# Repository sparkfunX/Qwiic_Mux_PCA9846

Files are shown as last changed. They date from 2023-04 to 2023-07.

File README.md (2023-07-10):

SparkFun PCA9846 Qwiic I2C Mux
===========================================================

SparkX Qwiic Mux - PCA9846 (SPX-22362) (https://www.sparkfun.com/products/22362)

[*SparkX Qwiic Mux - PCA9846 (SPX-22362)*](https://www.sparkfun.com/products/22362)

Do you have too many sensors with the same I<sup>2</sup>C address? Connect them to the SparkX PCA9846 Qwiic Mux to get them all talking on the same bus! This Qwiic Mux enables communication with multiple I<sup>2</sup>C devices that have the same address. This Qwiic Mux also has eight configurable addresses of its own, allowing for up to 32 I<sup>2</sup>C buses on a single connection. To make it even easier to use this multiplexer, all communication is enacted exclusively via I<sup>2</sup>C, utilizing our handy Qwiic system.

The PCA9846 Qwiic Mux is very similar to our classic [8-channel Qwiic Mux](https://www.sparkfun.com/products/16784), except:

* It has four multiplexed Qwiic ports, plus Qwiic Main In and Out connections, on a super-cute 1" x 1" PCB
* The PCA9846 has a "Who Am I" (Device ID) product identification register which makes it _much_ easier to detect in auto-detect DataLogger / OpenLog applications.

Feel like supporting open source hardware? 
Buy a [board](https://www.sparkfun.com/products/22362) from SparkFun!

Repository Contents
-------------------

* **/Documents** - Datasheet for the PCA9846
* **/Hardware** - Eagle CAD files for the PCB, schematic and dimensions

Arduino Library
--------------

* **[Arduino Library](https://github.com/sparkfun/SparkFun_PCA9846_Mux_Arduino_Library)** - Arduino Library for the PCA9846 I<sup>2</sup>C Mux
* **[Installing an Arduino Library Guide](https://learn.sparkfun.com/tutorials/installing-an-arduino-library)** - Basic information on how to install an Arduino library.

Address Configuration
--------------

The PCA9846 actually supports 16 I<sup>2</sup>C addresses, but to implement all 16 we would have had to include another three solder jumpers.
This is a busy little board, so we decided to only implement 8 configurable addresses.

The PCA9846 appears on two I2C addresses:

* The mux address defined by the A0-A4 jumpers
* Address 0x7C - which is used to read the Device ID

The default mux address is 0x70 (unshifted). You can change it by opening and closing (soldering) the five address jumper pads as follows:

**Jumper Address Selection (Unshifted):**

| Address | A4 | A3 | A2 | A1 | A0 |
|---|---|---|---|---|---|
| 0x70 | Open | Open | Open | Open | **Closed** |
| 0x71 | Open | Open | Open | **Closed** | Open |
| 0x72 | Open | Open | **Closed** | Open | Open |
| 0x73 | Open | **Closed** | Open | Open | Open |
| 0x74 | **Closed** | Open | Open | Open | **Closed** |
| 0x75 | **Closed** | Open | Open | **Closed** | Open |
| 0x76 | **Closed** | Open | **Closed** | Open | Open |
| 0x77 | **Closed** | **Closed** | Open | Open | Open |

License Information
-------------------

This product is _**open source**_! 

Please use, reuse, and modify these files as you see fit. Please maintain attribution to SparkFun Electronics and release anything derivative under the same license.

Distributed as-is; no warranty is given.

- Your friends at SparkFun.

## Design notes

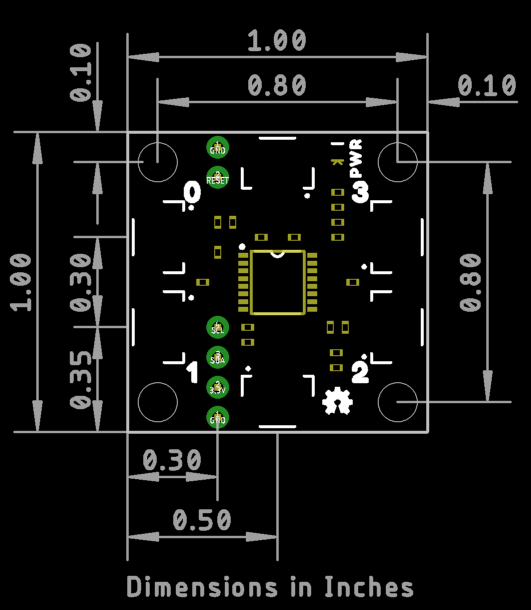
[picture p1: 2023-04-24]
Hardware/Dimensions.png

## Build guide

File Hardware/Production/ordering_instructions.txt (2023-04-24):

panel size, 169x117mm
PCB thickness, 1.6mm
number of layers, 2
soldermask color, Black
silkscreen color, White
oz copper, 1oz
finish, HASL lead free
stencils, top
pcs per panel, 24
min trace width, 0.1778mm / 0.0070in
min drill size, 0.3000mm / 0.0118in

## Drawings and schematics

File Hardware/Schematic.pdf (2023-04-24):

SD1 SD1 | SC1
SC1 SC1 | SD2

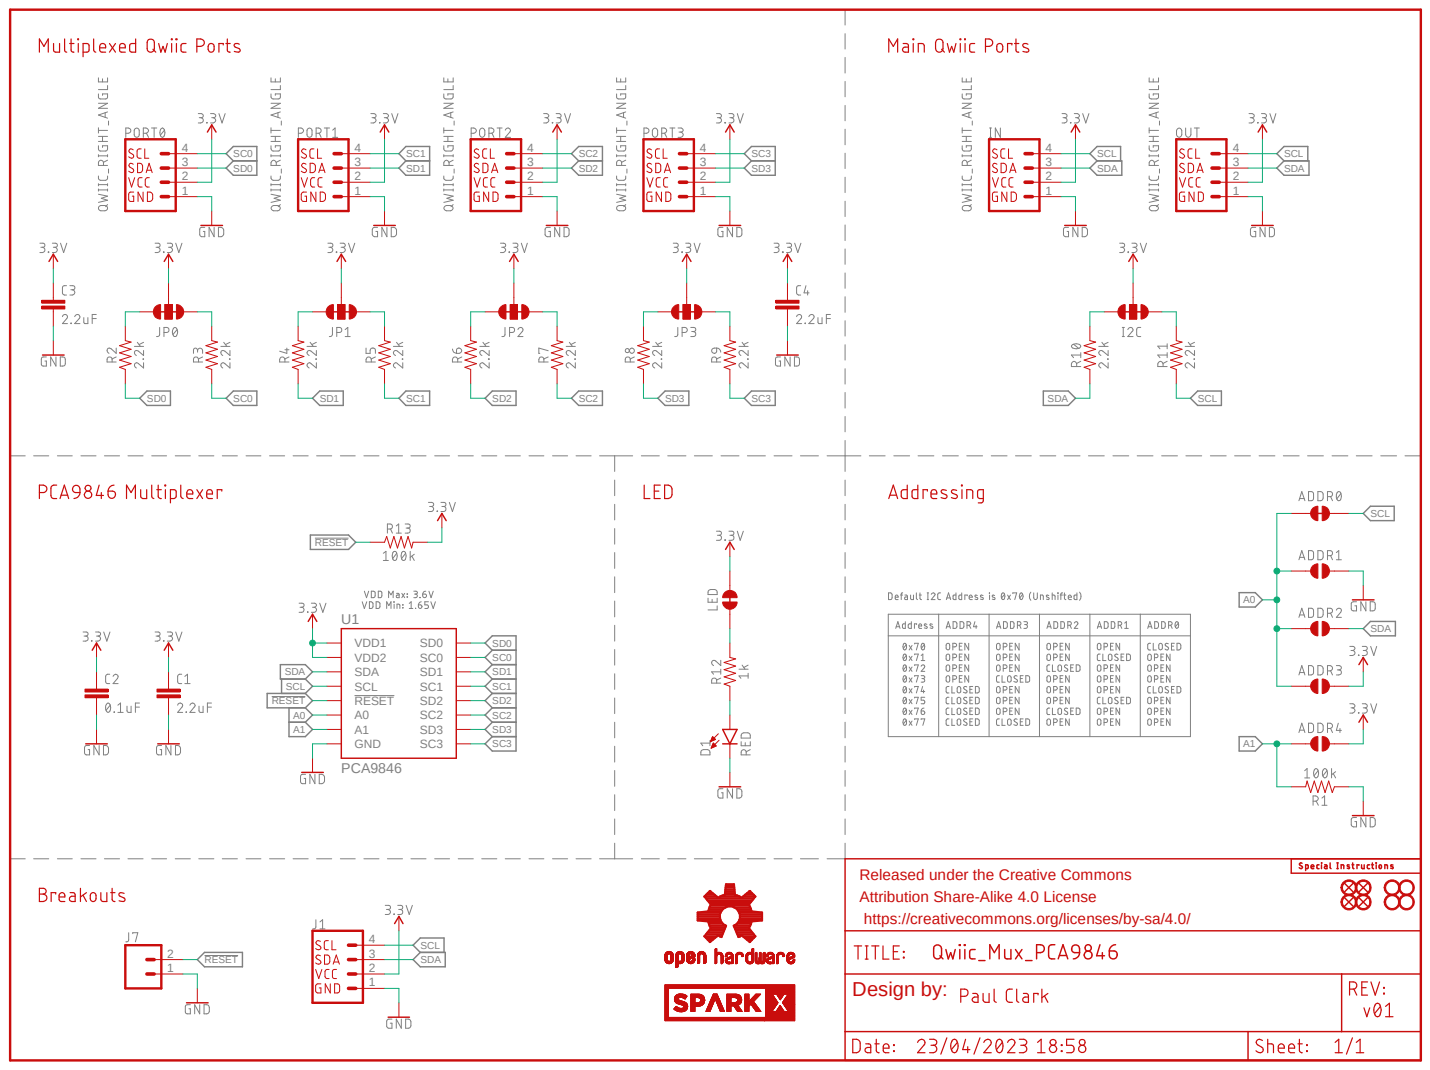
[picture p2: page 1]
PCA9846 SD0 A1SDA; SC3 SC3 SDA; SDA; SCL; RESET A0; A1 Released under the Creative Commons; Design by:

SCL RESET RESET

SD3 SC2 SC3 SD2 SD1 SC0 SC1 VDD2 U1
SCL A0VDD1 RESET GND

Attribution Share-Alike 4.0 License
https://creativecommons.org/licenses/by-sa/4.0/

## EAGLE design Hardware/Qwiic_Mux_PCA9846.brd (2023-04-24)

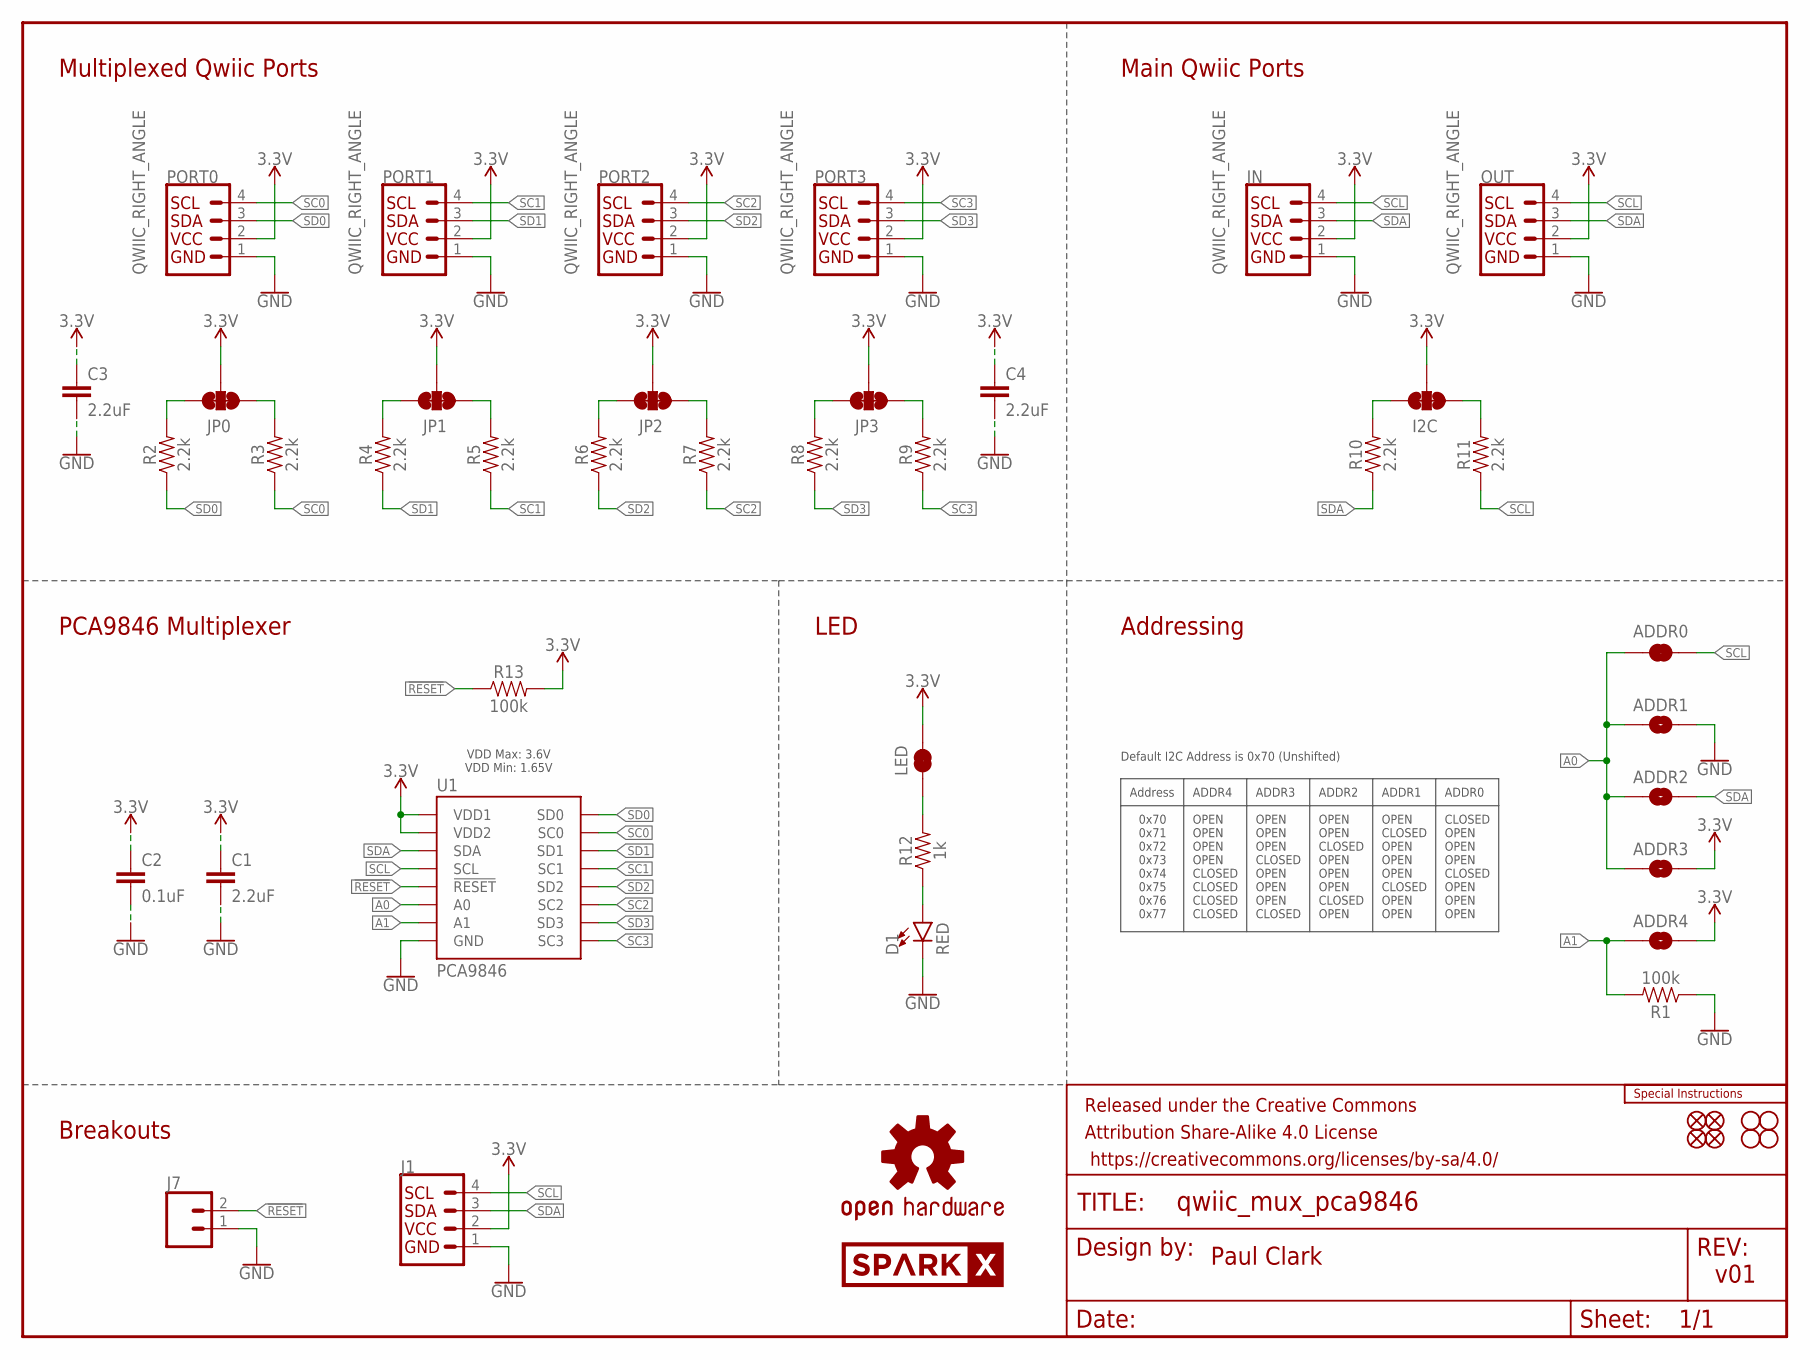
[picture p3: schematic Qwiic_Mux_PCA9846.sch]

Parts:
ADDR0: JUMPER-SMT_2_NC_TRACE_SILK; SMT-JUMPER_2_NC_TRACE_SILK
ADDR1, ADDR2, ADDR3, ADDR4: JUMPER-SMT_2_NO_SILK; SMT-JUMPER_2_NO_SILK
C1, C3, C4: 2.2uF; 0402-TIGHT
C2: 0.1uF; 0402-TIGHT
D1: RED; LED-0603
FD1, FD2, FD3, FD4: FIDUCIAL1X2; FIDUCIAL-1X2
FRAME1: FRAME-LETTER; CREATIVE_COMMONS
H1, H2, H3, H4: STAND-OFF
I2C: JUMPER-SMT_3_2-NC_TRACE_SILK; SMT-JUMPER_3_2-NC_TRACE_SILK
IN: QWIIC_RIGHT_ANGLE; JST04_1MM_RA
J1: I2C_STANDARD_NO_SILK; 1X04_NO_SILK
J7: CONN_021X02_NO_SILK; 1X02_NO_SILK
JP0, JP1, JP2, JP3: JUMPER-SMT_3_2-NC_TRACE_SILK; SMT-JUMPER_3_2-NC_TRACE_SILK
LED: JUMPER-SMT_2_NC_TRACE_SILK; SMT-JUMPER_2_NC_TRACE_SILK
LOGO1: SPECIAL_INSTRUCTIONS-ORDERING; ORDERING_INSTRUCTIONS
LOGO4: OSHW-LOGOMINI; OSHW-LOGO-MINI
OUT: QWIIC_RIGHT_ANGLE; JST04_1MM_RA
PORT0, PORT1, PORT2, PORT3: QWIIC_RIGHT_ANGLE; JST04_1MM_RA
R1, R13: 100k; 0402-TIGHT
R2, R3, R4, R5, R6, R7, R8, R9, R10, R11: 2.2k; 0402-TIGHT
R12: 1k; 0402-TIGHT
U1: PCA9846; SOT403-1
U$1: SPARKX-LOGO3; SPARKX-SMALL

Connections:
3.3V: ADDR3.2, ADDR4.2, C1.1, C2.1, C3.1, C4.1, I2C.2, IN.2, J1.2, JP0.2, JP1.2, JP2.2, JP3.2, LED.2, OUT.2, PORT0.2, PORT1.2, PORT2.2, PORT3.2, R13.2, U1.1 (VDD1), U1.16 (VDD2)
!RESET!: J7.2, R13.1, U1.3 (!RESET)
A0: ADDR0.1, ADDR1.1, ADDR2.1, ADDR3.1, U1.2 (A0)
A1: ADDR4.1, R1.2, U1.13 (A1)
GND: ADDR1.2, C1.2, C2.2, C3.2, C4.2, D1.C, IN.1, J1.1, J7.1, OUT.1, PORT0.1, PORT1.1, PORT2.1, PORT3.1, R1.1, U1.8 (GND)
unnamed: JP0.3, R2.2
unnamed: JP0.1, R3.2
unnamed: JP1.3, R4.2
unnamed: JP1.1, R5.2
unnamed: JP2.3, R6.2
unnamed: JP2.1, R7.2
unnamed: JP3.3, R8.2
unnamed: JP3.1, R9.2
unnamed: I2C.3, R10.2
unnamed: I2C.1, R11.2
unnamed: LED.1, R12.2
unnamed: D1.A, R12.1
SC0: PORT0.4, R3.1, U1.5 (SC0)
SC1: PORT1.4, R5.1, U1.7 (SC1)
SC2: PORT2.4, R7.1, U1.10 (SC2)
SC3: PORT3.4, R9.1, U1.12 (SC3)
SCL: ADDR0.2, IN.4, J1.4, OUT.4, R11.1, U1.14 (SCL)
SD0: PORT0.3, R2.1, U1.4 (SD0)
SD1: PORT1.3, R4.1, U1.6 (SD1)
SD2: PORT2.3, R6.1, U1.9 (SD2)
SD3: PORT3.3, R8.1, U1.11 (SD3)
SDA: ADDR2.2, IN.3, J1.3, OUT.3, R10.1, U1.15 (SDA)

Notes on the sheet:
Multiplexed Qwiic Ports
Main Qwiic Ports
PCA9846 Multiplexer
Addressing
Default I2C Address is 0x70 (Unshifted)
Address
ADDR4
ADDR3
ADDR2
ADDR1
ADDR0
0x70 0x71 0x72 0x73 0x74 0x75 0x76 0x77
OPEN OPEN OPEN OPEN CLOSED CLOSED CLOSED CLOSED
OPEN OPEN OPEN CLOSED OPEN OPEN OPEN CLOSED
CLOSED OPEN OPEN OPEN CLOSED OPEN OPEN OPEN
OPEN CLOSED OPEN OPEN OPEN CLOSED OPEN OPEN
OPEN OPEN CLOSED OPEN OPEN OPEN CLOSED OPEN
Paul Clark
v01
Breakouts
LED
VDD Max: 3.6V VDD Min: 1.65V

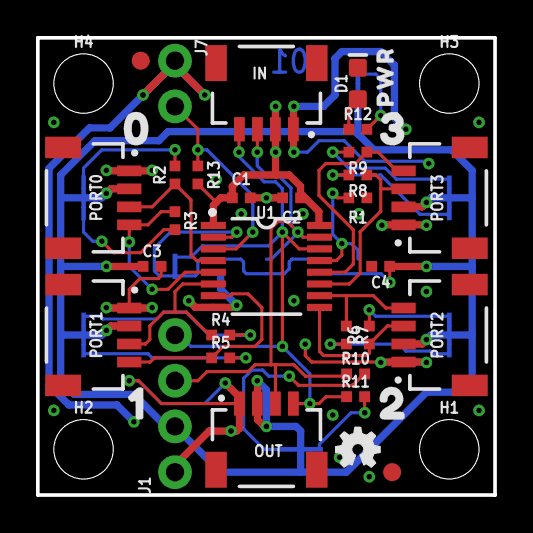
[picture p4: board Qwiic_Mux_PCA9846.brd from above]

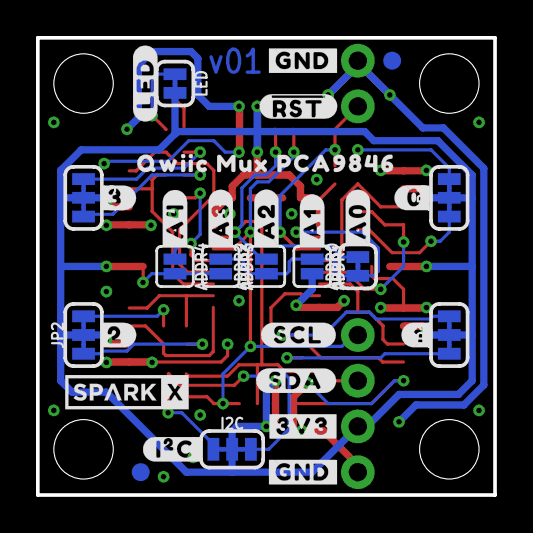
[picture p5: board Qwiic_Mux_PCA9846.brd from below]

Board: 2 copper layers, 25.4 x 25.4 mm, 73 parts (32 on the bottom side), 27 nets.

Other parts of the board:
U$2: PWR43214
U$3: 043215
U$4: 10
U$5: 211
U$6: 3212
U$7: ##RST##8
U$8: #0#9
U$9: #1#9
U$10: #2#9
U$11: #3#9
U$12: #3V3#7
U$13: #A0#0
U$14: #A1#1
U$15: #A2#2
U$16: #A3#3
U$17: #A4#4
U$18, U$19: #GND#7
U$21: #SCL#5
U$22: #SDA#6
U$23: #LED#0
U$24: QWIIC_MUX_PCA98461
U$25: #I�C#0

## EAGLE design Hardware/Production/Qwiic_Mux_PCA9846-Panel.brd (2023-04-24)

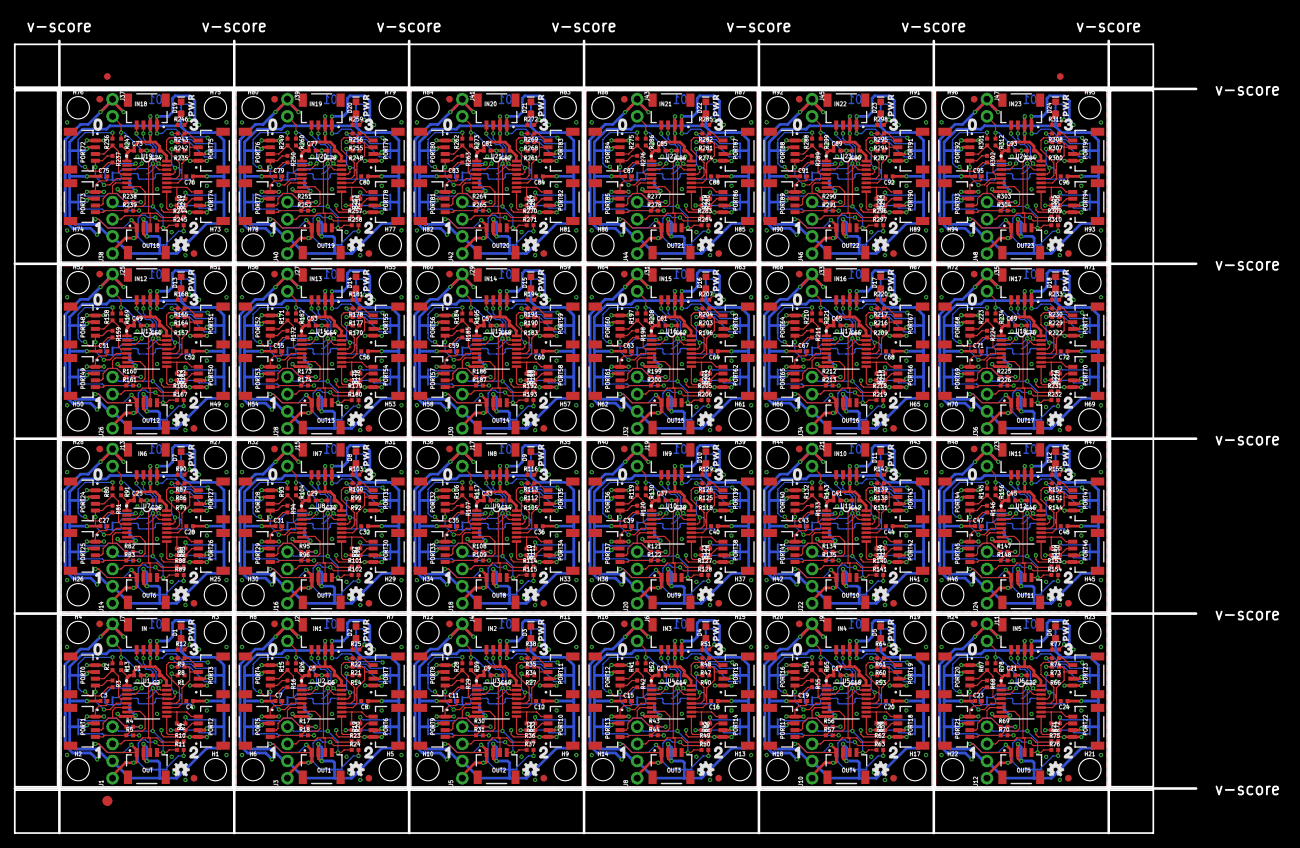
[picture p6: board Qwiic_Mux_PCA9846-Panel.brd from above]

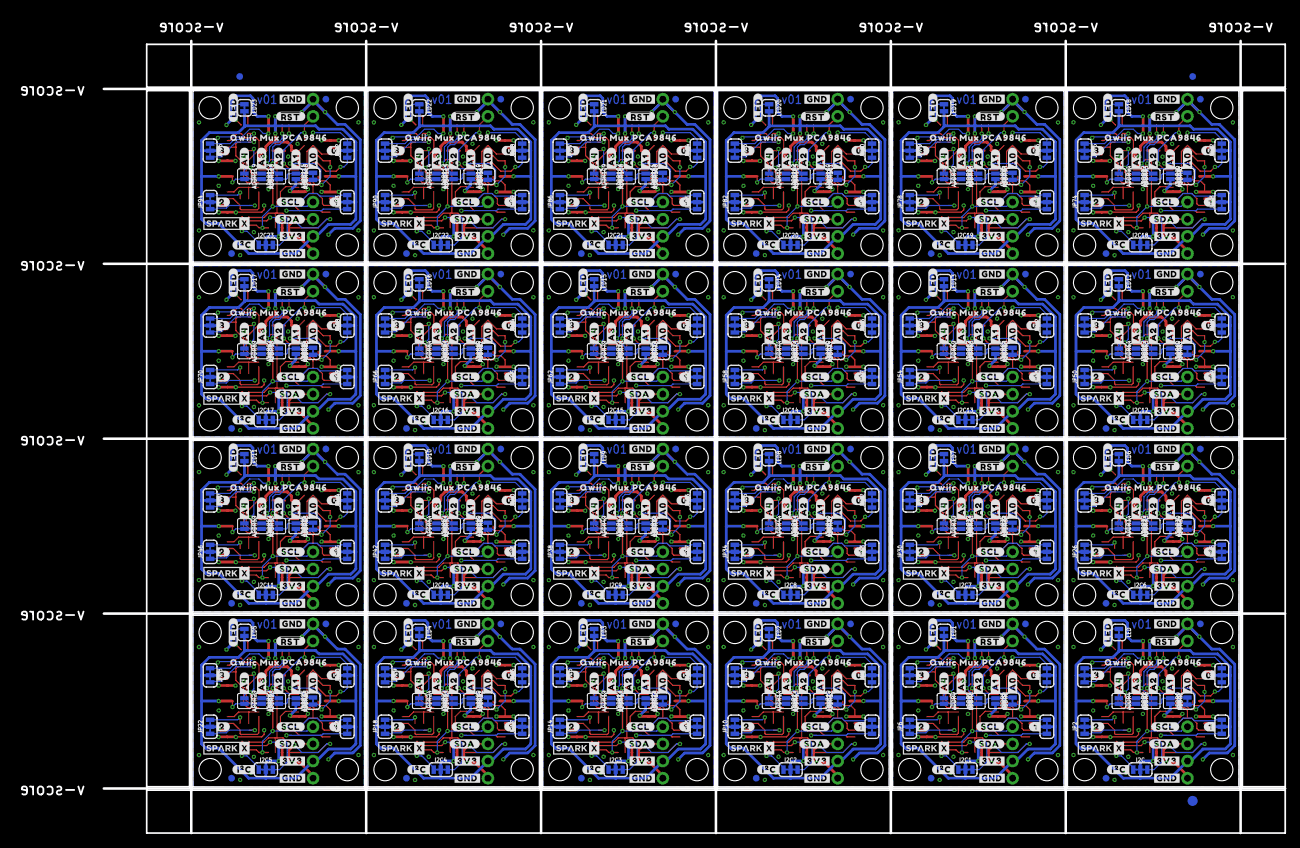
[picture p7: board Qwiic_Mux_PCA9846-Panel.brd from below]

Board: 2 copper layers, 175.0 x 117.3 mm, 1710 parts (771 on the bottom side), 648 nets.

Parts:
ADDR0, ADDR5, ADDR10, ADDR15, ADDR20, ADDR25, ADDR30, ADDR35, ADDR40, ADDR45, ADDR50, ADDR55, ADDR60, ADDR65, ADDR70, ADDR75, ADDR80, ADDR85, ADDR90, ADDR95, ADDR100, ADDR105, ADDR110, ADDR115: JUMPER-SMT_2_NC_TRACE_SILK; SMT-JUMPER_2_NC_TRACE_SILK
ADDR1, ADDR2, ADDR3, ADDR4, ADDR6, ADDR7, ADDR8, ADDR9, ADDR11, ADDR12, ADDR13, ADDR14, ADDR16, ADDR17, ADDR18, ADDR19, ADDR21, ADDR22, ADDR23, ADDR24, ADDR26, ADDR27, ADDR28, ADDR29, ADDR31, ADDR32, ADDR33, ADDR34, ADDR36, ADDR37, ADDR38, ADDR39, ADDR41, ADDR42, ADDR43, ADDR44, ADDR46, ADDR47, ADDR48, ADDR49, ADDR51, ADDR52, ADDR53, ADDR54, ADDR56, ADDR57, ADDR58, ADDR59, ADDR61, ADDR62, ADDR63, ADDR64, ADDR66, ADDR67, ADDR68, ADDR69, ADDR71, ADDR72, ADDR73, ADDR74, ADDR76, ADDR77, ADDR78, ADDR79, ADDR81, ADDR82, ADDR83, ADDR84, ADDR86, ADDR87, ADDR88, ADDR89, ADDR91, ADDR92, ADDR93, ADDR94, ADDR96, ADDR97, ADDR98, ADDR99, ADDR101, ADDR102, ADDR103, ADDR104, ADDR106, ADDR107, ADDR108, ADDR109, ADDR111, ADDR112, ADDR113, ADDR114, ADDR116, ADDR117, ADDR118, ADDR119: JUMPER-SMT_2_NO_SILK; SMT-JUMPER_2_NO_SILK
C1, C3, C4, C5, C7, C8, C9, C11, C12, C13, C15, C16, C17, C19, C20, C21, C23, C24, C25, C27, C28, C29, C31, C32, C33, C35, C36, C37, C39, C40, C41, C43, C44, C45, C47, C48, C49, C51, C52, C53, C55, C56, C57, C59, C60, C61, C63, C64, C65, C67, C68, C69, C71, C72, C73, C75, C76, C77, C79, C80, C81, C83, C84, C85, C87, C88, C89, C91, C92, C93, C95, C96: 2.2uF; 0402-TIGHT
C2, C6, C10, C14, C18, C22, C26, C30, C34, C38, C42, C46, C50, C54, C58, C62, C66, C70, C74, C78, C82, C86, C90, C94: 0.1uF; 0402-TIGHT
D1, D2, D3, D4, D5, D6, D7, D8, D9, D10, D11, D12, D13, D14, D15, D16, D17, D18, D19, D20, D21, D22, D23, D24: RED; LED-0603
E$1, E$2, E$3, E$4: FIDUCIAL-1X2
E$5, E$6: FIDUCIAL-1.5X3
FD1, FD2, FD3, FD4, FD5, FD6, FD7, FD8, FD9, FD10, FD11, FD12, FD13, FD14, FD15, FD16, FD17, FD18, FD19, FD20, FD21, FD22, FD23, FD24, FD25, FD26, FD27, FD28, FD29, FD30, FD31, FD32, FD33, FD34, FD35, FD36, FD37, FD38, FD39, FD40, FD41, FD42, FD43, FD44, FD45, FD46, FD47, FD48, FD49, FD50, FD51, FD52, FD53, FD54, FD55, FD56, FD57, FD58, FD59, FD60, FD61, FD62, FD63, FD64, FD65, FD66, FD67, FD68, FD69, FD70, FD71, FD72, FD73, FD74, FD75, FD76, FD77, FD78, FD79, FD80, FD81, FD82, FD83, FD84, FD85, FD86, FD87, FD88, FD89, FD90, FD91, FD92, FD93, FD94, FD95, FD96: FIDUCIAL1X2; FIDUCIAL-1X2
H1, H2, H3, H4, H5, H6, H7, H8, H9, H10, H11, H12, H13, H14, H15, H16, H17, H18, H19, H20, H21, H22, H23, H24, H25, H26, H27, H28, H29, H30, H31, H32, H33, H34, H35, H36, H37, H38, H39, H40, H41, H42, H43, H44, H45, H46, H47, H48, H49, H50, H51, H52, H53, H54, H55, H56, H57, H58, H59, H60, H61, H62, H63, H64, H65, H66, H67, H68, H69, H70, H71, H72, H73, H74, H75, H76, H77, H78, H79, H80, H81, H82, H83, H84, H85, H86, H87, H88, H89, H90, H91, H92, H93, H94, H95, H96: STAND-OFF
I2C, I2C1, I2C2, I2C3, I2C4, I2C5, I2C6, I2C7, I2C8, I2C9, I2C10, I2C11, I2C12, I2C13, I2C14, I2C15, I2C16, I2C17, I2C18, I2C19, I2C20, I2C21, I2C22, I2C23: JUMPER-SMT_3_2-NC_TRACE_SILK; SMT-JUMPER_3_2-NC_TRACE_SILK
IN, IN1, IN2, IN3, IN4, IN5, IN6, IN7, IN8, IN9, IN10, IN11, IN12, IN13, IN14, IN15, IN16, IN17, IN18, IN19, IN20, IN21, IN22, IN23: QWIIC_RIGHT_ANGLE; JST04_1MM_RA
J1, J3, J5, J8, J10, J12, J14, J16, J18, J20, J22, J24, J26, J28, J30, J32, J34, J36, J38, J40, J42, J44, J46, J48: 1X04_NO_SILK
J2, J4, J6, J7, J9, J11, J13, J15, J17, J19, J21, J23, J25, J27, J29, J31, J33, J35, J37, J39, J41, J43, J45, J47: 1X02_NO_SILK
JP0, JP1, JP2, JP3, JP4, JP5, JP6, JP7, JP8, JP9, JP10, JP11, JP12, JP13, JP14, JP15, JP16, JP17, JP18, JP19, JP20, JP21, JP22, JP23, JP24, JP25, JP26, JP27, JP28, JP29, JP30, JP31, JP32, JP33, JP34, JP35, JP36, JP37, JP38, JP39, JP40, JP41, JP42, JP43, JP44, JP45, JP46, JP47, JP48, JP49, JP50, JP51, JP52, JP53, JP54, JP55, JP56, JP57, JP58, JP59, JP60, JP61, JP62, JP63, JP64, JP65, JP66, JP67, JP68, JP69, JP70, JP71, JP72, JP73, JP74, JP75, JP76, JP77, JP78, JP79, JP80, JP81, JP82, JP83, JP84, JP85, JP86, JP87, JP88, JP89, JP90, JP91, JP92, JP93, JP94, JP95: JUMPER-SMT_3_2-NC_TRACE_SILK; SMT-JUMPER_3_2-NC_TRACE_SILK
LED, LED1, LED2, LED3, LED4, LED5, LED6, LED7, LED8, LED9, LED10, LED11, LED12, LED13, LED14, LED15, LED16, LED17, LED18, LED19, LED20, LED21, LED22, LED23: JUMPER-SMT_2_NC_TRACE_SILK; SMT-JUMPER_2_NC_TRACE_SILK
LOGO1, LOGO2, LOGO3, LOGO4, LOGO5, LOGO6, LOGO7, LOGO8, LOGO9, LOGO10, LOGO11, LOGO12, LOGO13, LOGO14, LOGO15, LOGO16, LOGO17, LOGO18, LOGO19, LOGO20, LOGO21, LOGO22, LOGO23, LOGO24: OSHW-LOGOMINI; OSHW-LOGO-MINI
OUT, OUT1, OUT2, OUT3, OUT4, OUT5, OUT6, OUT7, OUT8, OUT9, OUT10, OUT11, OUT12, OUT13, OUT14, OUT15, OUT16, OUT17, OUT18, OUT19, OUT20, OUT21, OUT22, OUT23: QWIIC_RIGHT_ANGLE; JST04_1MM_RA
PORT0, PORT1, PORT2, PORT3, PORT4, PORT5, PORT6, PORT7, PORT8, PORT9, PORT10, PORT11, PORT12, PORT13, PORT14, PORT15, PORT16, PORT17, PORT18, PORT19, PORT20, PORT21, PORT22, PORT23, PORT24, PORT25, PORT26, PORT27, PORT28, PORT29, PORT30, PORT31, PORT32, PORT33, PORT34, PORT35, PORT36, PORT37, PORT38, PORT39, PORT40, PORT41, PORT42, PORT43, PORT44, PORT45, PORT46, PORT47, PORT48, PORT49, PORT50, PORT51, PORT52, PORT53, PORT54, PORT55, PORT56, PORT57, PORT58, PORT59, PORT60, PORT61, PORT62, PORT63, PORT64, PORT65, PORT66, PORT67, PORT68, PORT69, PORT70, PORT71, PORT72, PORT73, PORT74, PORT75, PORT76, PORT77, PORT78, PORT79, PORT80, PORT81, PORT82, PORT83, PORT84, PORT85, PORT86, PORT87, PORT88, PORT89, PORT90, PORT91, PORT92, PORT93, PORT94, PORT95: QWIIC_RIGHT_ANGLE; JST04_1MM_RA
R1, R13, R14, R26, R27, R39, R40, R52, R53, R65, R66, R78, R79, R91, R92, R104, R105, R117, R118, R130, R131, R143, R144, R156, R157, R169, R170, R182, R183, R195, R196, R208, R209, R221, R222, R234, R235, R247, R248, R260, R261, R273, R274, R286, R287, R299, R300, R312: 100k; 0402-TIGHT
R2, R3, R4, R5, R6, R7, R8, R9, R10, R11, R15, R16, R17, R18, R19, R20, R21, R22, R23, R24, R28, R29, R30, R31, R32, R33, R34, R35, R36, R37, R41, R42, R43, R44, R45, R46, R47, R48, R49, R50, R54, R55, R56, R57, R58, R59, R60, R61, R62, R63, R67, R68, R69, R70, R71, R72, R73, R74, R75, R76, R80, R81, R82, R83, R84, R85, R86, R87, R88, R89, R93, R94, R95, R96, R97, R98, R99, R100, R101, R102, R106, R107, R108, R109, R110, R111, R112, R113, R114, R115, R119, R120, R121, R122, R123, R124, R125, R126, R127, R128, R132, R133, R134, R135, R136, R137, R138, R139, R140, R141, R145, R146, R147, R148, R149, R150, R151, R152, R153, R154, R158, R159, R160, R161, R162, R163, R164, R165, R166, R167, R171, R172, R173, R174, R175, R176, R177, R178, R179, R180, R184, R185, R186, R187, R188, R189, R190, R191, R192, R193, R197, R198, R199, R200, R201, R202, R203, R204, R205, R206, R210, R211, R212, R213, R214, R215, R216, R217, R218, R219, R223, R224, R225, R226, R227, R228, R229, R230, R231, R232, R236, R237, R238, R239, R240, R241, R242, R243, R244, R245, R249, R250, R251, R252, R253, R254, R255, R256, R257, R258, R262, R263, R264, R265, R266, R267, R268, R269, R270, R271, R275, R276, R277, R278, R279, R280, R281, R282, R283, R284, R288, R289, R290, R291, R292, R293, R294, R295, R296, R297, R301, R302, R303, R304, R305, R306, R307, R308, R309, R310: 2.2k; 0402-TIGHT
R12, R25, R38, R51, R64, R77, R90, R103, R116, R129, R142, R155, R168, R181, R194, R207, R220, R233, R246, R259, R272, R285, R298, R311: 1k; 0402-TIGHT
U1, U2, U3, U4, U5, U6, U7, U8, U9, U10, U11, U12, U13, U14, U15, U16, U17, U18, U19, U20, U21, U22, U23, U24: PCA9846; SOT403-1
U$1, U$20, U$49, U$73, U$97, U$121, U$145, U$169, U$193, U$217, U$241, U$265, U$289, U$313, U$337, U$361, U$385, U$409, U$433, U$457, U$481, U$505, U$529, U$553: SPARKX-LOGO3; SPARKX-SMALL
U$2, U$26, U$50, U$74, U$98, U$122, U$146, U$170, U$194, U$218, U$242, U$266, U$290, U$314, U$338, U$362, U$386, U$410, U$434, U$458, U$482, U$506, U$530, U$554: PWR43214
U$3, U$27, U$51, U$75, U$99, U$123, U$147, U$171, U$195, U$219, U$243, U$267, U$291, U$315, U$339, U$363, U$387, U$411, U$435, U$459, U$483, U$507, U$531, U$555: 043215
U$4, U$28, U$52, U$76, U$100, U$124, U$148, U$172, U$196, U$220, U$244, U$268, U$292, U$316, U$340, U$364, U$388, U$412, U$436, U$460, U$484, U$508, U$532, U$556: 10
U$5, U$29, U$53, U$77, U$101, U$125, U$149, U$173, U$197, U$221, U$245, U$269, U$293, U$317, U$341, U$365, U$389, U$413, U$437, U$461, U$485, U$509, U$533, U$557: 211
U$6, U$30, U$54, U$78, U$102, U$126, U$150, U$174, U$198, U$222, U$246, U$270, U$294, U$318, U$342, U$366, U$390, U$414, U$438, U$462, U$486, U$510, U$534, U$558: 3212
U$7, U$31, U$55, U$79, U$103, U$127, U$151, U$175, U$199, U$223, U$247, U$271, U$295, U$319, U$343, U$367, U$391, U$415, U$439, U$463, U$487, U$511, U$535, U$559: ##RST##8
U$8, U$32, U$56, U$80, U$104, U$128, U$152, U$176, U$200, U$224, U$248, U$272, U$296, U$320, U$344, U$368, U$392, U$416, U$440, U$464, U$488, U$512, U$536, U$560: #0#9
U$9, U$33, U$57, U$81, U$105, U$129, U$153, U$177, U$201, U$225, U$249, U$273, U$297, U$321, U$345, U$369, U$393, U$417, U$441, U$465, U$489, U$513, U$537, U$561: #1#9
U$10, U$34, U$58, U$82, U$106, U$130, U$154, U$178, U$202, U$226, U$250, U$274, U$298, U$322, U$346, U$370, U$394, U$418, U$442, U$466, U$490, U$514, U$538, U$562: #2#9
U$11, U$35, U$59, U$83, U$107, U$131, U$155, U$179, U$203, U$227, U$251, U$275, U$299, U$323, U$347, U$371, U$395, U$419, U$443, U$467, U$491, U$515, U$539, U$563: #3#9
U$12, U$36, U$60, U$84, U$108, U$132, U$156, U$180, U$204, U$228, U$252, U$276, U$300, U$324, U$348, U$372, U$396, U$420, U$444, U$468, U$492, U$516, U$540, U$564: #3V3#7
U$13, U$37, U$61, U$85, U$109, U$133, U$157, U$181, U$205, U$229, U$253, U$277, U$301, U$325, U$349, U$373, U$397, U$421, U$445, U$469, U$493, U$517, U$541, U$565: #A0#0
U$14, U$38, U$62, U$86, U$110, U$134, U$158, U$182, U$206, U$230, U$254, U$278, U$302, U$326, U$350, U$374, U$398, U$422, U$446, U$470, U$494, U$518, U$542, U$566: #A1#1
U$15, U$39, U$63, U$87, U$111, U$135, U$159, U$183, U$207, U$231, U$255, U$279, U$303, U$327, U$351, U$375, U$399, U$423, U$447, U$471, U$495, U$519, U$543, U$567: #A2#2
U$16, U$40, U$64, U$88, U$112, U$136, U$160, U$184, U$208, U$232, U$256, U$280, U$304, U$328, U$352, U$376, U$400, U$424, U$448, U$472, U$496, U$520, U$544, U$568: #A3#3
U$17, U$41, U$65, U$89, U$113, U$137, U$161, U$185, U$209, U$233, U$257, U$281, U$305, U$329, U$353, U$377, U$401, U$425, U$449, U$473, U$497, U$521, U$545, U$569: #A4#4
U$18, U$19, U$42, U$43, U$66, U$67, U$90, U$91, U$114, U$115, U$138, U$139, U$162, U$163, U$186, U$187, U$210, U$211, U$234, U$235, U$258, U$259, U$282, U$283, U$306, U$307, U$330, U$331, U$354, U$355, U$378, U$379, U$402, U$403, U$426, U$427, U$450, U$451, U$474, U$475, U$498, U$499, U$522, U$523, U$546, U$547, U$570, U$571: #GND#7
U$21, U$44, U$68, U$92, U$116, U$140, U$164, U$188, U$212, U$236, U$260, U$284, U$308, U$332, U$356, U$380, U$404, U$428, U$452, U$476, U$500, U$524, U$548, U$572: #SCL#5
U$22, U$45, U$69, U$93, U$117, U$141, U$165, U$189, U$213, U$237, U$261, U$285, U$309, U$333, U$357, U$381, U$405, U$429, U$453, U$477, U$501, U$525, U$549, U$573: #SDA#6
U$23, U$46, U$70, U$94, U$118, U$142, U$166, U$190, U$214, U$238, U$262, U$286, U$310, U$334, U$358, U$382, U$406, U$430, U$454, U$478, U$502, U$526, U$550, U$574: #LED#0
U$24, U$47, U$71, U$95, U$119, U$143, U$167, U$191, U$215, U$239, U$263, U$287, U$311, U$335, U$359, U$383, U$407, U$431, U$455, U$479, U$503, U$527, U$551, U$575: QWIIC_MUX_PCA98461
U$25, U$48, U$72, U$96, U$120, U$144, U$168, U$192, U$216, U$240, U$264, U$288, U$312, U$336, U$360, U$384, U$408, U$432, U$456, U$480, U$504, U$528, U$552, U$576: #I�C#0

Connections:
3.3V: ADDR3.2, ADDR4.2, C1.1, C2.1, C3.1, C4.1, I2C.2, IN.2, J1.2, JP0.2, JP1.2, JP2.2, JP3.2, LED.2, OUT.2, PORT0.2, PORT1.2, PORT2.2, PORT3.2, R13.2, U1.1, U1.16
3.3V1: ADDR8.2, ADDR9.2, C5.1, C6.1, C7.1, C8.1, I2C1.2, IN1.2, J3.2, JP4.2, JP5.2, JP6.2, JP7.2, LED1.2, OUT1.2, PORT4.2, PORT5.2, PORT6.2, PORT7.2, R26.2, U2.1, U2.16
3.3V2: ADDR13.2, ADDR14.2, C9.1, C10.1, C11.1, C12.1, I2C2.2, IN2.2, J5.2, JP8.2, JP9.2, JP10.2, JP11.2, LED2.2, OUT2.2, PORT8.2, PORT9.2, PORT10.2, PORT11.2, R39.2, U3.1, U3.16
3.3V3: ADDR18.2, ADDR19.2, C13.1, C14.1, C15.1, C16.1, I2C3.2, IN3.2, J8.2, JP12.2, JP13.2, JP14.2, JP15.2, LED3.2, OUT3.2, PORT12.2, PORT13.2, PORT14.2, PORT15.2, R52.2, U4.1, U4.16
3.3V4: ADDR23.2, ADDR24.2, C17.1, C18.1, C19.1, C20.1, I2C4.2, IN4.2, J10.2, JP16.2, JP17.2, JP18.2, JP19.2, LED4.2, OUT4.2, PORT16.2, PORT17.2, PORT18.2, PORT19.2, R65.2, U5.1, U5.16
3.3V5: ADDR28.2, ADDR29.2, C21.1, C22.1, C23.1, C24.1, I2C5.2, IN5.2, J12.2, JP20.2, JP21.2, JP22.2, JP23.2, LED5.2, OUT5.2, PORT20.2, PORT21.2, PORT22.2, PORT23.2, R78.2, U6.1, U6.16
3.3V6: ADDR33.2, ADDR34.2, C25.1, C26.1, C27.1, C28.1, I2C6.2, IN6.2, J14.2, JP24.2, JP25.2, JP26.2, JP27.2, LED6.2, OUT6.2, PORT24.2, PORT25.2, PORT26.2, PORT27.2, R91.2, U7.1, U7.16
3.3V7: ADDR38.2, ADDR39.2, C29.1, C30.1, C31.1, C32.1, I2C7.2, IN7.2, J16.2, JP28.2, JP29.2, JP30.2, JP31.2, LED7.2, OUT7.2, PORT28.2, PORT29.2, PORT30.2, PORT31.2, R104.2, U8.1, U8.16
3.3V8: ADDR43.2, ADDR44.2, C33.1, C34.1, C35.1, C36.1, I2C8.2, IN8.2, J18.2, JP32.2, JP33.2, JP34.2, JP35.2, LED8.2, OUT8.2, PORT32.2, PORT33.2, PORT34.2, PORT35.2, R117.2, U9.1, U9.16
3.3V9: ADDR48.2, ADDR49.2, C37.1, C38.1, C39.1, C40.1, I2C9.2, IN9.2, J20.2, JP36.2, JP37.2, JP38.2, JP39.2, LED9.2, OUT9.2, PORT36.2, PORT37.2, PORT38.2, PORT39.2, R130.2, U10.1, U10.16
3.3V10: ADDR53.2, ADDR54.2, C41.1, C42.1, C43.1, C44.1, I2C10.2, IN10.2, J22.2, JP40.2, JP41.2, JP42.2, JP43.2, LED10.2, OUT10.2, PORT40.2, PORT41.2, PORT42.2, PORT43.2, R143.2, U11.1, U11.16
3.3V11: ADDR58.2, ADDR59.2, C45.1, C46.1, C47.1, C48.1, I2C11.2, IN11.2, J24.2, JP44.2, JP45.2, JP46.2, JP47.2, LED11.2, OUT11.2, PORT44.2, PORT45.2, PORT46.2, PORT47.2, R156.2, U12.1, U12.16
3.3V12: ADDR63.2, ADDR64.2, C49.1, C50.1, C51.1, C52.1, I2C12.2, IN12.2, J26.2, JP48.2, JP49.2, JP50.2, JP51.2, LED12.2, OUT12.2, PORT48.2, PORT49.2, PORT50.2, PORT51.2, R169.2, U13.1, U13.16
3.3V13: ADDR68.2, ADDR69.2, C53.1, C54.1, C55.1, C56.1, I2C13.2, IN13.2, J28.2, JP52.2, JP53.2, JP54.2, JP55.2, LED13.2, OUT13.2, PORT52.2, PORT53.2, PORT54.2, PORT55.2, R182.2, U14.1, U14.16
3.3V14: ADDR73.2, ADDR74.2, C57.1, C58.1, C59.1, C60.1, I2C14.2, IN14.2, J30.2, JP56.2, JP57.2, JP58.2, JP59.2, LED14.2, OUT14.2, PORT56.2, PORT57.2, PORT58.2, PORT59.2, R195.2, U15.1, U15.16
3.3V15: ADDR78.2, ADDR79.2, C61.1, C62.1, C63.1, C64.1, I2C15.2, IN15.2, J32.2, JP60.2, JP61.2, JP62.2, JP63.2, LED15.2, OUT15.2, PORT60.2, PORT61.2, PORT62.2, PORT63.2, R208.2, U16.1, U16.16
3.3V16: ADDR83.2, ADDR84.2, C65.1, C66.1, C67.1, C68.1, I2C16.2, IN16.2, J34.2, JP64.2, JP65.2, JP66.2, JP67.2, LED16.2, OUT16.2, PORT64.2, PORT65.2, PORT66.2, PORT67.2, R221.2, U17.1, U17.16
3.3V17: ADDR88.2, ADDR89.2, C69.1, C70.1, C71.1, C72.1, I2C17.2, IN17.2, J36.2, JP68.2, JP69.2, JP70.2, JP71.2, LED17.2, OUT17.2, PORT68.2, PORT69.2, PORT70.2, PORT71.2, R234.2, U18.1, U18.16
3.3V18: ADDR93.2, ADDR94.2, C73.1, C74.1, C75.1, C76.1, I2C18.2, IN18.2, J38.2, JP72.2, JP73.2, JP74.2, JP75.2, LED18.2, OUT18.2, PORT72.2, PORT73.2, PORT74.2, PORT75.2, R247.2, U19.1, U19.16
3.3V19: ADDR98.2, ADDR99.2, C77.1, C78.1, C79.1, C80.1, I2C19.2, IN19.2, J40.2, JP76.2, JP77.2, JP78.2, JP79.2, LED19.2, OUT19.2, PORT76.2, PORT77.2, PORT78.2, PORT79.2, R260.2, U20.1, U20.16
3.3V20: ADDR103.2, ADDR104.2, C81.1, C82.1, C83.1, C84.1, I2C20.2, IN20.2, J42.2, JP80.2, JP81.2, JP82.2, JP83.2, LED20.2, OUT20.2, PORT80.2, PORT81.2, PORT82.2, PORT83.2, R273.2, U21.1, U21.16
3.3V21: ADDR108.2, ADDR109.2, C85.1, C86.1, C87.1, C88.1, I2C21.2, IN21.2, J44.2, JP84.2, JP85.2, JP86.2, JP87.2, LED21.2, OUT21.2, PORT84.2, PORT85.2, PORT86.2, PORT87.2, R286.2, U22.1, U22.16
3.3V22: ADDR113.2, ADDR114.2, C89.1, C90.1, C91.1, C92.1, I2C22.2, IN22.2, J46.2, JP88.2, JP89.2, JP90.2, JP91.2, LED22.2, OUT22.2, PORT88.2, PORT89.2, PORT90.2, PORT91.2, R299.2, U23.1, U23.16
3.3V23: ADDR118.2, ADDR119.2, C93.1, C94.1, C95.1, C96.1, I2C23.2, IN23.2, J48.2, JP92.2, JP93.2, JP94.2, JP95.2, LED23.2, OUT23.2, PORT92.2, PORT93.2, PORT94.2, PORT95.2, R312.2, U24.1, U24.16
!RESET!: J7.2, R13.1, U1.3
!RESET!1: J2.2, R26.1, U2.3
!RESET!2: J4.2, R39.1, U3.3
!RESET!3: J6.2, R52.1, U4.3
!RESET!4: J9.2, R65.1, U5.3
!RESET!5: J11.2, R78.1, U6.3
!RESET!6: J13.2, R91.1, U7.3
!RESET!7: J15.2, R104.1, U8.3
!RESET!8: J17.2, R117.1, U9.3
!RESET!9: J19.2, R130.1, U10.3
!RESET!10: J21.2, R143.1, U11.3
!RESET!11: J23.2, R156.1, U12.3
!RESET!12: J25.2, R169.1, U13.3
!RESET!13: J27.2, R182.1, U14.3
!RESET!14: J29.2, R195.1, U15.3
!RESET!15: J31.2, R208.1, U16.3
!RESET!16: J33.2, R221.1, U17.3
!RESET!17: J35.2, R234.1, U18.3
!RESET!18: J37.2, R247.1, U19.3
!RESET!19: J39.2, R260.1, U20.3
!RESET!20: J41.2, R273.1, U21.3
!RESET!21: J43.2, R286.1, U22.3
!RESET!22: J45.2, R299.1, U23.3
!RESET!23: J47.2, R312.1, U24.3
A0: ADDR0.1, ADDR1.1, ADDR2.1, ADDR3.1, U1.2
A1: ADDR4.1, R1.2, U1.13
A2: ADDR5.1, ADDR6.1, ADDR7.1, ADDR8.1, U2.2
A3: ADDR9.1, R14.2, U2.13
A4: ADDR10.1, ADDR11.1, ADDR12.1, ADDR13.1, U3.2
A5: ADDR14.1, R27.2, U3.13
A6: ADDR15.1, ADDR16.1, ADDR17.1, ADDR18.1, U4.2
A7: ADDR19.1, R40.2, U4.13
A8: ADDR20.1, ADDR21.1, ADDR22.1, ADDR23.1, U5.2
A9: ADDR24.1, R53.2, U5.13
A10: ADDR25.1, ADDR26.1, ADDR27.1, ADDR28.1, U6.2
A11: ADDR29.1, R66.2, U6.13
A12: ADDR30.1, ADDR31.1, ADDR32.1, ADDR33.1, U7.2
A13: ADDR34.1, R79.2, U7.13
A14: ADDR35.1, ADDR36.1, ADDR37.1, ADDR38.1, U8.2
A15: ADDR39.1, R92.2, U8.13
A16: ADDR40.1, ADDR41.1, ADDR42.1, ADDR43.1, U9.2
A17: ADDR44.1, R105.2, U9.13
A18: ADDR45.1, ADDR46.1, ADDR47.1, ADDR48.1, U10.2
A19: ADDR49.1, R118.2, U10.13
A20: ADDR50.1, ADDR51.1, ADDR52.1, ADDR53.1, U11.2
A21: ADDR54.1, R131.2, U11.13
A22: ADDR55.1, ADDR56.1, ADDR57.1, ADDR58.1, U12.2
A23: ADDR59.1, R144.2, U12.13
A24: ADDR60.1, ADDR61.1, ADDR62.1, ADDR63.1, U13.2
A25: ADDR64.1, R157.2, U13.13
A26: ADDR65.1, ADDR66.1, ADDR67.1, ADDR68.1, U14.2
A27: ADDR69.1, R170.2, U14.13
A28: ADDR70.1, ADDR71.1, ADDR72.1, ADDR73.1, U15.2
A29: ADDR74.1, R183.2, U15.13
A30: ADDR75.1, ADDR76.1, ADDR77.1, ADDR78.1, U16.2
A31: ADDR79.1, R196.2, U16.13
A32: ADDR80.1, ADDR81.1, ADDR82.1, ADDR83.1, U17.2
A33: ADDR84.1, R209.2, U17.13
A34: ADDR85.1, ADDR86.1, ADDR87.1, ADDR88.1, U18.2
A35: ADDR89.1, R222.2, U18.13
A36: ADDR90.1, ADDR91.1, ADDR92.1, ADDR93.1, U19.2
A37: ADDR94.1, R235.2, U19.13
A38: ADDR95.1, ADDR96.1, ADDR97.1, ADDR98.1, U20.2
A39: ADDR99.1, R248.2, U20.13
A40: ADDR100.1, ADDR101.1, ADDR102.1, ADDR103.1, U21.2
A41: ADDR104.1, R261.2, U21.13
A42: ADDR105.1, ADDR106.1, ADDR107.1, ADDR108.1, U22.2
A43: ADDR109.1, R274.2, U22.13
A44: ADDR110.1, ADDR111.1, ADDR112.1, ADDR113.1, U23.2
A45: ADDR114.1, R287.2, U23.13
A46: ADDR115.1, ADDR116.1, ADDR117.1, ADDR118.1, U24.2
A47: ADDR119.1, R300.2, U24.13
GND: ADDR1.2, C1.2, C2.2, C3.2, C4.2, D1.C, IN.1, J1.1, J7.1, OUT.1, PORT0.1, PORT1.1, PORT2.1, PORT3.1, R1.1, U1.8
GND1: ADDR6.2, C5.2, C6.2, C7.2, C8.2, D2.C, IN1.1, J2.1, J3.1, OUT1.1, PORT4.1, PORT5.1, PORT6.1, PORT7.1, R14.1, U2.8
GND2: ADDR11.2, C9.2, C10.2, C11.2, C12.2, D3.C, IN2.1, J4.1, J5.1, OUT2.1, PORT8.1, PORT9.1, PORT10.1, PORT11.1, R27.1, U3.8
GND3: ADDR16.2, C13.2, C14.2, C15.2, C16.2, D4.C, IN3.1, J6.1, J8.1, OUT3.1, PORT12.1, PORT13.1, PORT14.1, PORT15.1, R40.1, U4.8
GND4: ADDR21.2, C17.2, C18.2, C19.2, C20.2, D5.C, IN4.1, J9.1, J10.1, OUT4.1, PORT16.1, PORT17.1, PORT18.1, PORT19.1, R53.1, U5.8
GND5: ADDR26.2, C21.2, C22.2, C23.2, C24.2, D6.C, IN5.1, J11.1, J12.1, OUT5.1, PORT20.1, PORT21.1, PORT22.1, PORT23.1, R66.1, U6.8
GND6: ADDR31.2, C25.2, C26.2, C27.2, C28.2, D7.C, IN6.1, J13.1, J14.1, OUT6.1, PORT24.1, PORT25.1, PORT26.1, PORT27.1, R79.1, U7.8
GND7: ADDR36.2, C29.2, C30.2, C31.2, C32.2, D8.C, IN7.1, J15.1, J16.1, OUT7.1, PORT28.1, PORT29.1, PORT30.1, PORT31.1, R92.1, U8.8
GND8: ADDR41.2, C33.2, C34.2, C35.2, C36.2, D9.C, IN8.1, J17.1, J18.1, OUT8.1, PORT32.1, PORT33.1, PORT34.1, PORT35.1, R105.1, U9.8
GND9: ADDR46.2, C37.2, C38.2, C39.2, C40.2, D10.C, IN9.1, J19.1, J20.1, OUT9.1, PORT36.1, PORT37.1, PORT38.1, PORT39.1, R118.1, U10.8
GND10: ADDR51.2, C41.2, C42.2, C43.2, C44.2, D11.C, IN10.1, J21.1, J22.1, OUT10.1, PORT40.1, PORT41.1, PORT42.1, PORT43.1, R131.1, U11.8
GND11: ADDR56.2, C45.2, C46.2, C47.2, C48.2, D12.C, IN11.1, J23.1, J24.1, OUT11.1, PORT44.1, PORT45.1, PORT46.1, PORT47.1, R144.1, U12.8
GND12: ADDR61.2, C49.2, C50.2, C51.2, C52.2, D13.C, IN12.1, J25.1, J26.1, OUT12.1, PORT48.1, PORT49.1, PORT50.1, PORT51.1, R157.1, U13.8
GND13: ADDR66.2, C53.2, C54.2, C55.2, C56.2, D14.C, IN13.1, J27.1, J28.1, OUT13.1, PORT52.1, PORT53.1, PORT54.1, PORT55.1, R170.1, U14.8
GND14: ADDR71.2, C57.2, C58.2, C59.2, C60.2, D15.C, IN14.1, J29.1, J30.1, OUT14.1, PORT56.1, PORT57.1, PORT58.1, PORT59.1, R183.1, U15.8
GND15: ADDR76.2, C61.2, C62.2, C63.2, C64.2, D16.C, IN15.1, J31.1, J32.1, OUT15.1, PORT60.1, PORT61.1, PORT62.1, PORT63.1, R196.1, U16.8
GND16: ADDR81.2, C65.2, C66.2, C67.2, C68.2, D17.C, IN16.1, J33.1, J34.1, OUT16.1, PORT64.1, PORT65.1, PORT66.1, PORT67.1, R209.1, U17.8
GND17: ADDR86.2, C69.2, C70.2, C71.2, C72.2, D18.C, IN17.1, J35.1, J36.1, OUT17.1, PORT68.1, PORT69.1, PORT70.1, PORT71.1, R222.1, U18.8
GND18: ADDR91.2, C73.2, C74.2, C75.2, C76.2, D19.C, IN18.1, J37.1, J38.1, OUT18.1, PORT72.1, PORT73.1, PORT74.1, PORT75.1, R235.1, U19.8
GND19: ADDR96.2, C77.2, C78.2, C79.2, C80.2, D20.C, IN19.1, J39.1, J40.1, OUT19.1, PORT76.1, PORT77.1, PORT78.1, PORT79.1, R248.1, U20.8
GND20: ADDR101.2, C81.2, C82.2, C83.2, C84.2, D21.C, IN20.1, J41.1, J42.1, OUT20.1, PORT80.1, PORT81.1, PORT82.1, PORT83.1, R261.1, U21.8
GND21: ADDR106.2, C85.2, C86.2, C87.2, C88.2, D22.C, IN21.1, J43.1, J44.1, OUT21.1, PORT84.1, PORT85.1, PORT86.1, PORT87.1, R274.1, U22.8
GND22: ADDR111.2, C89.2, C90.2, C91.2, C92.2, D23.C, IN22.1, J45.1, J46.1, OUT22.1, PORT88.1, PORT89.1, PORT90.1, PORT91.1, R287.1, U23.8
GND23: ADDR116.2, C93.2, C94.2, C95.2, C96.2, D24.C, IN23.1, J47.1, J48.1, OUT23.1, PORT92.1, PORT93.1, PORT94.1, PORT95.1, R300.1, U24.8
unnamed: JP0.3, R2.2
unnamed: JP0.1, R3.2
unnamed: JP1.3, R4.2
unnamed: JP1.1, R5.2
unnamed: JP2.3, R6.2
unnamed: JP2.1, R7.2
unnamed: JP3.3, R8.2
unnamed: JP3.1, R9.2
unnamed: I2C.3, R10.2
unnamed: I2C.1, R11.2
unnamed: LED.1, R12.2
unnamed: D1.A, R12.1
unnamed: JP4.3, R15.2
unnamed: JP4.1, R16.2
unnamed: JP5.3, R17.2
unnamed: JP5.1, R18.2
unnamed: JP6.3, R19.2
unnamed: JP6.1, R20.2
unnamed: JP7.3, R21.2
unnamed: JP7.1, R22.2
unnamed: I2C1.3, R23.2
unnamed: I2C1.1, R24.2
unnamed: LED1.1, R25.2
unnamed: D2.A, R25.1
unnamed: JP8.3, R28.2
unnamed: JP8.1, R29.2
unnamed: JP9.3, R30.2
unnamed: JP9.1, R31.2
unnamed: JP10.3, R32.2
unnamed: JP10.1, R33.2
unnamed: JP11.3, R34.2
unnamed: JP11.1, R35.2
unnamed: I2C2.3, R36.2
unnamed: I2C2.1, R37.2
unnamed: LED2.1, R38.2
unnamed: D3.A, R38.1
unnamed: JP12.3, R41.2
unnamed: JP12.1, R42.2
unnamed: JP13.3, R43.2
unnamed: JP13.1, R44.2
unnamed: JP14.3, R45.2
unnamed: JP14.1, R46.2
unnamed: JP15.3, R47.2
unnamed: JP15.1, R48.2
unnamed: I2C3.3, R49.2
unnamed: I2C3.1, R50.2
unnamed: LED3.1, R51.2
unnamed: D4.A, R51.1
unnamed: JP16.3, R54.2
unnamed: JP16.1, R55.2
unnamed: JP17.3, R56.2
unnamed: JP17.1, R57.2
unnamed: JP18.3, R58.2
unnamed: JP18.1, R59.2
unnamed: JP19.3, R60.2
unnamed: JP19.1, R61.2
unnamed: I2C4.3, R62.2
unnamed: I2C4.1, R63.2
unnamed: LED4.1, R64.2
unnamed: D5.A, R64.1
unnamed: JP20.3, R67.2
unnamed: JP20.1, R68.2
unnamed: JP21.3, R69.2
unnamed: JP21.1, R70.2
unnamed: JP22.3, R71.2
unnamed: JP22.1, R72.2
unnamed: JP23.3, R73.2
unnamed: JP23.1, R74.2
unnamed: I2C5.3, R75.2
unnamed: I2C5.1, R76.2
unnamed: LED5.1, R77.2
unnamed: D6.A, R77.1
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

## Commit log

2023-04-24 Ready for review
    [Qwiic_Mux_PCA9846-Panel.GBL, Qwiic_Mux_PCA9846-Panel.GBP, Qwiic_Mux_PCA9846-Panel.GBS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]
2023-04-24 Add PROD_ID
    [Qwiic_Mux_PCA9846-Panel.brd, Qwiic_Mux_PCA9846.brd, Qwiic_Mux_PCA9846.sch]

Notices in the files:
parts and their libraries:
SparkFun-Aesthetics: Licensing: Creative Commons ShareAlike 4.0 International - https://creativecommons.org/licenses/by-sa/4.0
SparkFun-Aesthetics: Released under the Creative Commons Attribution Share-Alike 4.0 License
